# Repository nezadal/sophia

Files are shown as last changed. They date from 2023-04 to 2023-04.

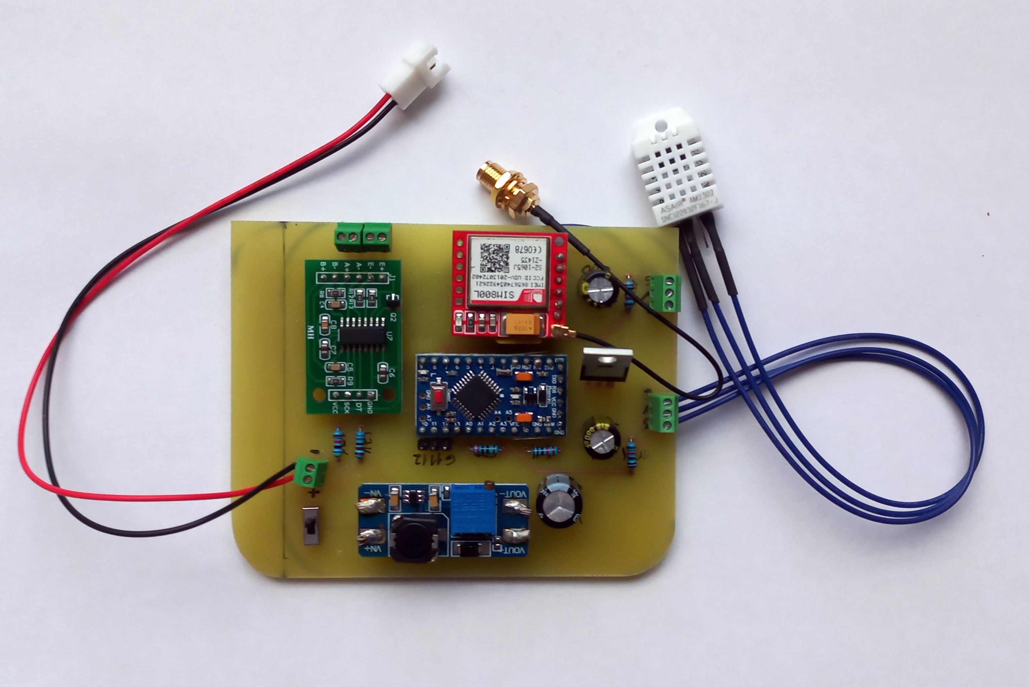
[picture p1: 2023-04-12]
prototyp.jpg

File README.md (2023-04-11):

# Sophia
Bee Hive Scale with GSM data tranfer to ThingSpeak server, runs on battery with solar panel charging. Bee Hive Scale monitors bee hive weight, temperature, humidity and voltage of battery. These values are measured hourly, trasfered and stored to ThingSpeak server. 

Hardware:

- Arduino Pro Mini, 3,3V,
- 4x loadcell, a 50kg,
- HX711 amplifier,
- 2x 18650 3,7 V Lion cell,
- DHT 22 humidity and temperature sensor,
- MT3608 step-up,
- IRL 540 NPBF transistor,
- SIM800L GSM modul,
- Solar panel 6V, 4,5W,
- Solar charger module CN 3791, 6V, 
- some resistors, capacitators, wiring, switch...

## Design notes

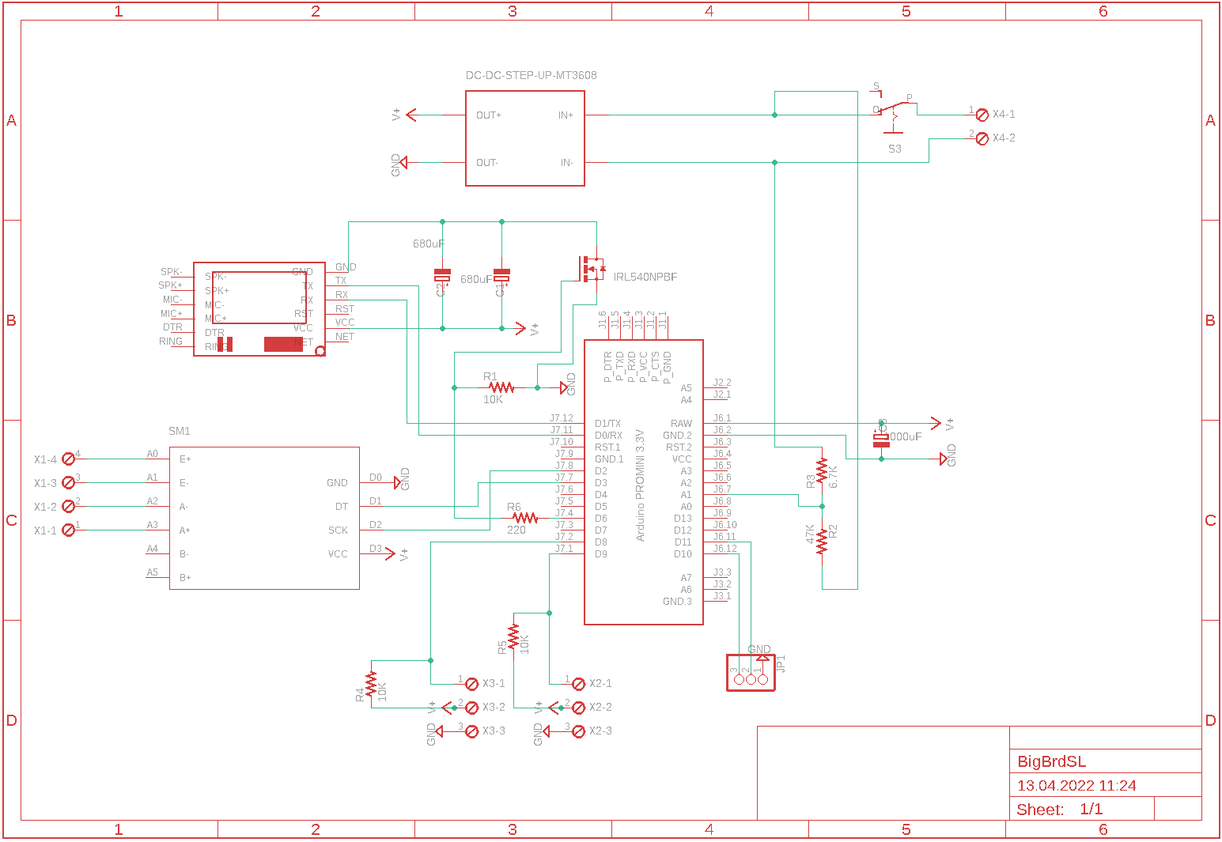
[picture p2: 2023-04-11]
schematics.png

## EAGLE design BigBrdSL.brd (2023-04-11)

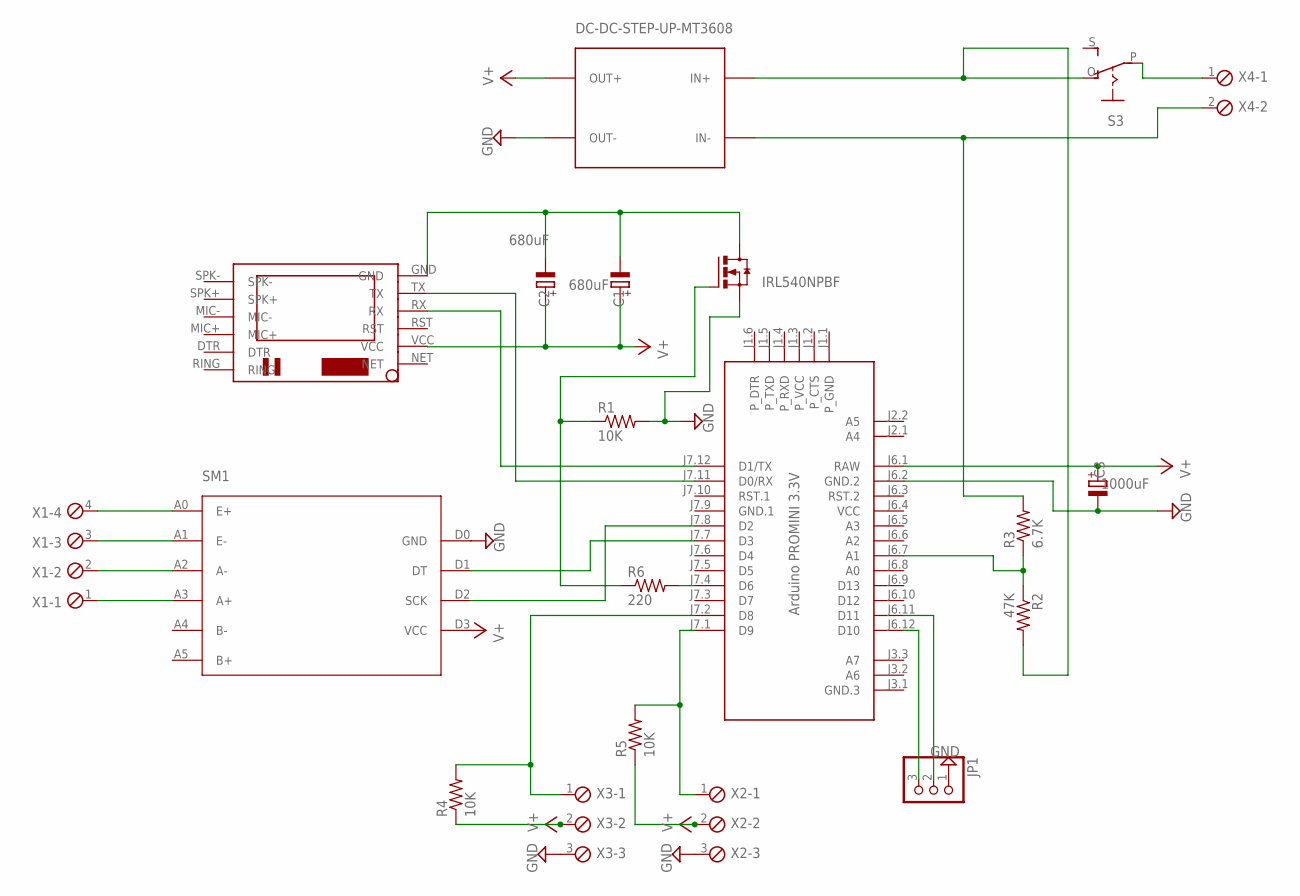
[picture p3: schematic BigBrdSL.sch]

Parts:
C1, C2: 680uF; E3,5-8
C3: 1000uF; E3,5-8
IRL540NPBF: IRF520NPBF; TO-220; MPN IRL540NPBF; DIGIKEY_PART_NUMBER IRlL540NPBF
JP1: PINHD-1X3; 1X03
M1: ARDUINO-PRO-MINI-5.0V; ARDUINO-PRO-MINI
MT36-08: DC-DC-STEP-UP-MT3608
R1, R4, R5: 10K; 0207/7
R2: 47K; 0207/7
R3: 6.7K; 0207/7
R6: 220; 0207/7
S3: EG1218S; EG1218
SM1: HX711
U$3: SIM800LMODULE
X1: MPT4; 4POL254
X2, X3: MPT3; 3POL254
X4: MPT2; 2POL254

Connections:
GND: C3.-, IRL540NPBF.S, JP1.1, M1.J6.2 (GND.2), MT36-08.OUT-, R1.2, SM1.D0 (GND), X2.3, X3.3
GND.1: M1.J7.9 (GND.1)
unnamed: M1.J7.1 (D9), R5.2, X2.1
unnamed: MT36-08.IN+, R2.2, S3.O
unnamed: IRL540NPBF.G, R1.1, R6.1
unnamed: M1.J7.11 (D0/RX), U$3.TX
unnamed: M1.J7.7 (D3), SM1.D1 (DT)
unnamed: M1.J7.12 (D1/TX), U$3.RX
unnamed: M1.J7.8 (D2), SM1.D2 (SCK)
unnamed: JP1.3, M1.J6.12 (D10)
unnamed: M1.J7.4 (D6), R6.2
unnamed: MT36-08.IN-, R3.2, X4.2
unnamed: M1.J6.7 (A1), R2.1, R3.1
unnamed: C1.-, C2.-, IRL540NPBF.D, U$3.GND
unnamed: JP1.2, M1.J6.11 (D11)
unnamed: SM1.A0 (E+), X1.4
unnamed: SM1.A1 (E-), X1.3
unnamed: SM1.A2 (A-), X1.2
unnamed: SM1.A3 (A+), X1.1
unnamed: S3.P, X4.1
unnamed: M1.J7.2 (D8), R4.2, X3.1
V+: C1.+, C2.+, C3.+, M1.J6.1 (RAW), MT36-08.OUT+, R4.1, R5.1, SM1.D3 (VCC), U$3.VCC, X2.2, X3.2
VCC: M1.J6.4 (VCC)

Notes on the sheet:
Arduino PROMINI 3.3V

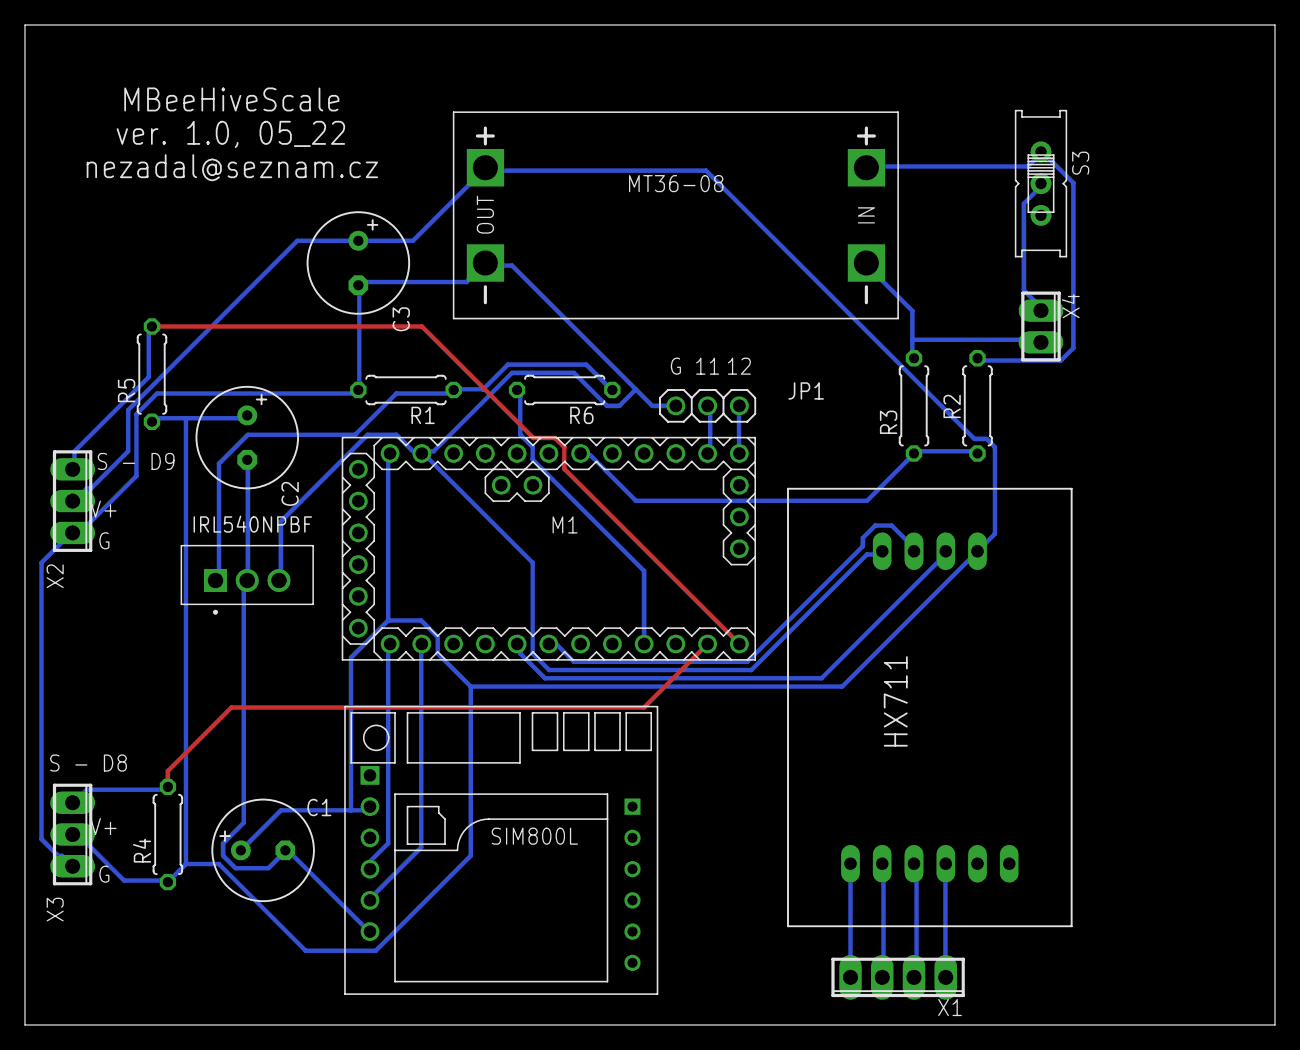
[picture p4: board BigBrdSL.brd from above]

Board: 2 copper layers, 100.0 x 80.0 mm, 20 parts (0 on the bottom side), 21 nets.

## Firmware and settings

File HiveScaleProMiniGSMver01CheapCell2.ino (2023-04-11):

#include <DHT.h>
#include <SoftwareSerial.h>     
#include "HX711.h"
#include "LowPower.h"
#include <GSMSimHTTP.h>
                       
#define interval 75 // interval pro čtení hodnot čidel a jejich odesílání v násobcích 8s. Bezplatná verze ThingSpeak umožňuje minimální interval 15 000 ms.  
// 375 - 60 minut
// 187 - 30 minut
// 75 - 12 minut   
// 8 - cca minuta    

/////// Měření hmotnosti  ////////////////////////////////////////////////
// konstanty pro můstkovou váhu
//#define calibration_factor -25500.0 //This value is obtained using the SparkFun_HX711_Calibration sketch
//#define offset 8.45
//#define tempcorr 0.0134
//  2x loadcell
///#define calibration_factor -26880.0 //This value is obtained using the SparkFun_HX711_Calibration sketc
//////#define calibration_factor -25500.0 //This value is obtained using the SparkFun_HX711_Calibration sketch - Poloviční můstek

// Červená váha, 4x load cell - E+ fialová, E- žlutá, A+ šedá, A- modrá
#define calibration_factor -20600
#define offset -30.6
#define tempcorr 0.0205
#define tempcal 20


// Modrá váha - E+ zelená, E- červená, A+ černá, A- bílá
//#define calibration_factor -25300 
//#define offset 8.7
//#define tempcorr 0.0095
//#define tempcal 20

 
 

// teplota, při které byla měřena kalibrace

#define DOUT  3
#define CLK  2
HX711 scale;
float weight;

/////// Měření teploty a vlhkosti ////////////////////////////////////////////////
#define DHTPIN 9          // pin pro připojení teplotního a vlhkostního sensoru
#define DHTTYPE DHT22     // typ teplotně-vlhkostního čidla - může být DHT22
DHT dht(DHTPIN, DHTTYPE); 
float hum;                                    
float temp;  

/////// SIM karta, připojení ////////////////////////////////////////////////////
#define RESET_PIN 8 // you can use any pin.
#define SIMPWR_PIN 6 // červená, stříbrná váha
//#define SIMPWR_PIN 5 // modrá váha
//static volatile int num = 0;
GSMSimHTTP http(Serial, RESET_PIN); // GSMSimHíTTP inherit from GSMSimGPRS. You can use GSMSim and GSMSimGPRS methods with it.
//// nastavení jména serveru, ke kterému se chceme připojit
String gprsServer = "api.thingspeak.com";
//// nastavení ukládacího API pro ThingSpeak
String API = "PZFG108LGVQHWH3F"; // stříbrná váha
////String API = "0MI5IBLE4137224H"; // červená váha
////String API = "F5DWVQP4W90CFYUY"; // modrá váha


//// Počet pokusů o připojení k GPRS před resetem
int Ecount = 3;  

  


/////// Debug ////////////////////////////////////////////////////
SoftwareSerial debug(10, 11);


/////// Měření napětí baterie ////////////////////////////////////////////////////
int voltageinput = A1;
float vout = 0.0;
float vin = 0.0;
float R1 = 46600.0;  
float R2 = 6720.0; 
 

int voltage = 0;

boolean alarmsent;        // byl poslán alarm? Poslán = true, neposlán = false.                    

void setup()
{
  pinMode(SIMPWR_PIN, OUTPUT);  
  digitalWrite(SIMPWR_PIN, HIGH);
  delay(500);
  debug.begin(57600); 
  alarmsent = false;    
    
  
  /// Teplota a vlhkost
  dht.begin();    
  
  /// Hmotnost
  scale.begin(DOUT, CLK);
  scale.set_scale(calibration_factor); //This value is obtained by using the SparkFun_HX711_Calibration sketch
//  scale.tare(); //Assuming there is no weight on the scale at start up, reset the scale to 0
//  debug.println("Váha nulována, OK");   

  /// Měření napětí
  analogReference(INTERNAL); 
  pinMode(voltageinput, INPUT);   
  
             
}

void AlarmCheck()
// Zkontroluje magnetický senzor. 
// Pokud je rozpojený, a alarmsent je false, odešle SMS na udané číslo. 
//      Pokud je odeslání v pořádku, nastaví globální proměnnou alarmsent na true.
// Pokud je spojený nastaví alarmsent na false.
{
  
}



void ReadTemperatureHumidity()
// načte do globálních float hum a temp vlhkost a teplotu
{

   hum = dht.readHumidity();                 
   temp = dht.readTemperature();
      
   if (isnan(hum) || isnan(temp))    
   // Pokud je chyba čtení, vypíše na sériovou linku hlášení, počká 2,5 s a zopakuje čtení.          
      {
         debug.println("Chyba cteni!"); 
         delay(2500);   
         hum = dht.readHumidity();                 
         temp = dht.readTemperature();
     
       }
  // pokud jsou obě hodnoty v pořádku, tak:
     else                                       
   {
    debug.print("Vlhkost: ");                
    debug.print(hum);
    debug.print(" %, Teplota: ");
    debug.print(temp);
    debug.println(" Celsius");

  }
}  
  
void ReadWeight()
// načte do globální proměnné float weight hmotnost úlu
{             
  // print the average of 5 readings from the ADC minus tare weight, divided
  // by the SCALE parameter set with set_scale
  weight = (scale.get_units(3));
  weight = weight - offset;
  // korelace na teplotu
  weight = weight + tempcorr*(tempcal-temp);
  debug.print("Hmotnost: ");
  debug.println(weight);

 
}

void ReadBattery()
// načte do globální proměnné float battery voltage baterie vin
{
  int poc;
  int avgvoltage = 0;
  poc = 0;
  voltage = 0;
  // prumer z 5ti mereni s mezerou 500 ms
   for(poc=1;poc<6;poc++){ 
     voltage = analogRead(voltageinput);
     avgvoltage = avgvoltage + voltage;
     delay(500);
   }
   voltage = avgvoltage/5;
   debug.print("voltage ");
   debug.print(voltage);
   vout = (voltage *1.1) / 1024.0; // spravne ma b7t hodnota Vint 1.1V
   debug.print("vout ");
   debug.print(vout); 
   vin = vout / (R2/(R1+R2));
//   vin = vout / 0.2359;
   debug.print("Napětí baterie: ");
   debug.println(vin,3);
}




//
//void BuzzerBeep(int bcount)
//{
//  for (int i = 0; i < bcount; i++){
//  tone(buzzer, 1000, 250);
//  delay(500);
//  
//  }
//}
//
//
//void BuzzerSucc()
//{
//  for (int i = 1; i < 6; i++){
//  tone(buzzer, i*1000, 100);
//  delay(200);
//  
//  }
//}
//
//void BuzzerEndLoop()
//{
//  for (int i = 1; i < 12; i++){
//  tone(buzzer, i*500, 50);
//  delay(100);
//  
//  }
//}
//
//void BuzzerFail()
//{
//  for (int i = 3; i > 0; i--){
//  tone(buzzer, i*1000, 250);
//  delay(500);
//  
//  }
//}

boolean SendDataToThingSpeak() {
 boolean isregistered = 1;
 boolean isconnected = 1;
 debug.println("StartSEnding");
 digitalWrite(SIMPWR_PIN, HIGH);
 delay(2000);
 Serial.begin(57600); 
  while(!Serial) {
    debug.println("Cekam na sběrnici"); // wait for module for connect.
  }

  http.init(); // use for init module. Use it if you dont have any valid reason.
  int poc = 0;
  debug.println("INIT_Set Phone Function...");
  do{
    delay(2000);
    poc++;
  }while (!http.setPhoneFunc(1) == 1);   
  delay(500);
  debug.println(http.setPhoneFunc(1));

  
  debug.println("is Module Registered to Network?");
  poc = 0;
  do{
    delay(2000);
    poc++;
    if (poc > 9) {
      isregistered = 0;
      break;      
    }
  }while (!http.isRegistered() == 1);   
  delay(500);
  if (isregistered) {
    debug.print("registrováno do sítě po ");
    debug.print(poc);
    debug.println("x2 s");
  }
  else {
    debug.println("Neregistrováno do sítě");
    }

  debug.println("Connect GPRS");
  poc = 0;
  do{
    delay(2000);
    poc++;
    debug.println(poc);
    if (poc > 9) {
       isconnected = 0;
       break;
       
    }
  }while (!http.connect() == 1); 
  delay(500);  
  if (isconnected) {
    debug.print("Připojeno k GPRS po  ");
    debug.print(poc);
    debug.println("x2 s");
  }
  else {
    debug.println("Nepřipojeno k GPRS datům");
    }
  
  String zprava = gprsServer; 
  zprava += "/update?api_key=";
  zprava += API;
  zprava += "&field1=";
  zprava += hum;
  zprava += "&field2=";
  zprava += temp;
  zprava += "&field3=";
  zprava += weight;
  zprava += "&field4=";
  zprava += vin;
  debug.println(zprava);
  String odezva = (http.get(zprava));
  debug.println(odezva);
  delay(500);
  debug.print("Close GPRS... ");
  debug.println(http.closeConn());
  
  // Vypnutí
  poc = 0;
  debug.print("Vypnuti SIM modulu... ");
  delay(1000);
  do{
    delay(1000);
    poc++;
  }while (!http.setPhoneFunc(4) == 1);  
  
  debug.print("Vypnuto po ");
  debug.print(poc);
  debug.println(" s");
  digitalWrite(SIMPWR_PIN, LOW);
  
  if (odezva.substring(11,23) == "HTTPCODE:200"){
    return true;
  }
  else {
    return false;
  } 

}


void loop()
{
  //AlarmCheck;
    delay(1000);
    ReadTemperatureHumidity(); 
    ReadWeight();
    ReadBattery();
    
   int poc = 0;
   do {
    poc++;
    if (poc > 3) {
      debug.println("Odeslání po 3 pokusech neúspěšné, usínám...");
      break;
    }
   } while (!SendDataToThingSpeak() == 1); 
   debug.println("Odeslání úspěšné, usínám...");
    for (int i = 0; i <=  interval; i++) {
     LowPower.powerDown(SLEEP_8S, ADC_OFF, BOD_OFF); 
   }
}


                              

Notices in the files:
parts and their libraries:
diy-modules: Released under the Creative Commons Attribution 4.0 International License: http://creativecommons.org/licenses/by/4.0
